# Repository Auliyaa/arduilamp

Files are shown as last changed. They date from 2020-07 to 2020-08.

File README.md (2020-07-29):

# arduilamp

## Description

This repository holds the code as well as the STL files and PCB design to create a RGB lamp with an Arduino board.

The lamp itself supports several modes for speed, brightness & animation, all of which are cycled using 3 buttons connected to the controller.

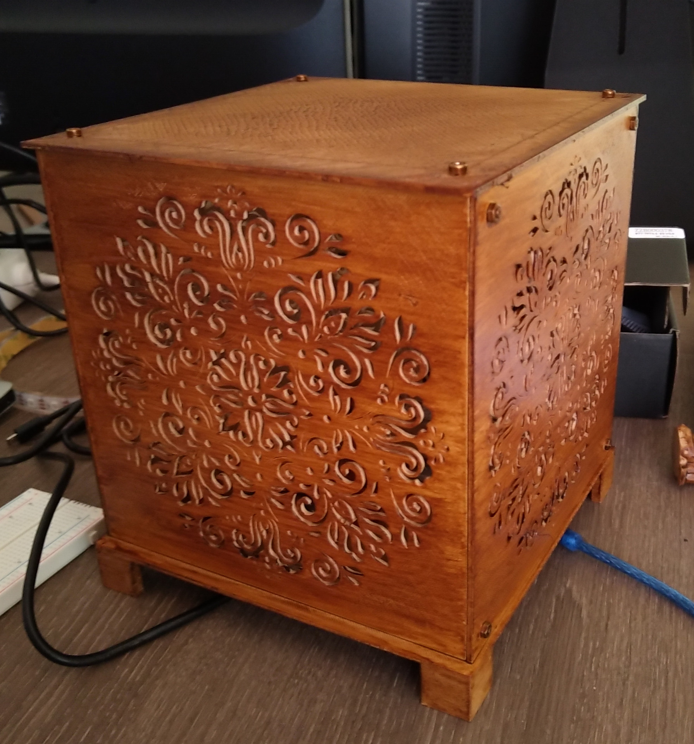
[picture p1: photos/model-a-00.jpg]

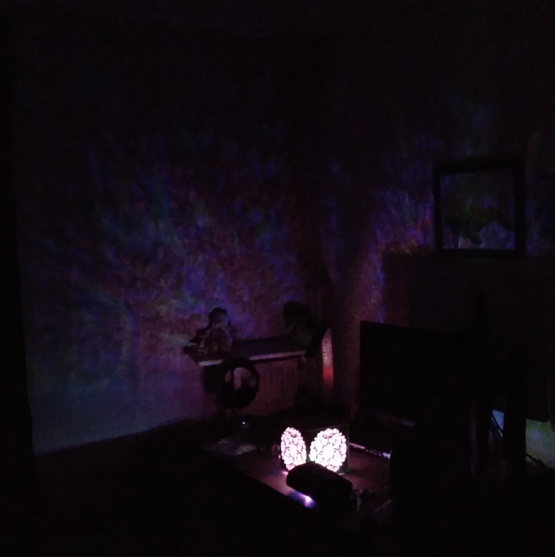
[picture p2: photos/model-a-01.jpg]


## BOM

You'll also need a make of the PCB available under the **pcb** folder as well as a print of one of the lamp models (see the **stl/** folder for details).
The rest of the BOM is the same for all lamp models.

| Piece  | Count  | Link  | Note |
|---|---|---|---|
| Arduino nano ATmega238P | x1  | [Amazon](https://www.amazon.fr/gp/product/B0722YYBSS/ref=ppx_yo_dt_b_asin_title_o07_s00?ie=UTF8&psc=1) | |
| 5V power plug | x1 | [Amazon](https://www.amazon.fr/gp/product/B07G953WC3/ref=ppx_yo_dt_b_asin_title_o09_s01?ie=UTF8&psc=1) | Since those are micro USB, I had to use a [Micro usb to mini USB breakout adapter board](https://www.amazon.fr/gp/product/B07R9SMJKF/ref=ppx_yo_dt_b_asin_title_o02_s00?ie=UTF8&psc=1) |
| WS2812B strip | x1 | [Amazon](https://www.amazon.fr/gp/product/B00JR0MJIU/ref=ppx_yo_dt_b_asin_title_o09_s01?ie=UTF8&psc=1) | |
| 10 kOhm resistor | x3 | [Amazon](https://www.amazon.fr/gp/product/B071LHFQKD/ref=ppx_yo_dt_b_asin_title_o07_s00?ie=UTF8&psc=1) | |
| Push button | x3 | [Amazon](https://www.amazon.fr/gp/product/B01E6SBB5E/ref=ppx_yo_dt_b_search_asin_title?ie=UTF8&psc=1) | |

Not included are tools like wires, soldering iron, a 3D printer and some tools to clean-up your prints.

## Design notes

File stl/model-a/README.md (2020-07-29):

Original design credits to [vishnu1505](https://www.thingiverse.com/thing:2955149).
You'll need to print 2x **Shade_with_holes.STL** and 2x **Shade_with_mount.STL** for the sides. Skip the other files.
Instead use the **Base.stl** and **Top_cover.stl** provided in this repository for the top & bottom pieces.

Those were printed on a Creality Ender-3 using wood PLA.

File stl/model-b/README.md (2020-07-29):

Original design credits to [Agent_Cain](https://www.thingiverse.com/thing:2974862).

I used the original design without modification, using the Top_Hard variant and without printing any of the Plane.stl files.

Then I hot glued the top section over the base after puting a square of 2x2 LEDs inside it.

The code was modified accordingly to set LED group size to 4 (see board.h).

Printed on a Creality Ender 3 with SmartFil white PLA.

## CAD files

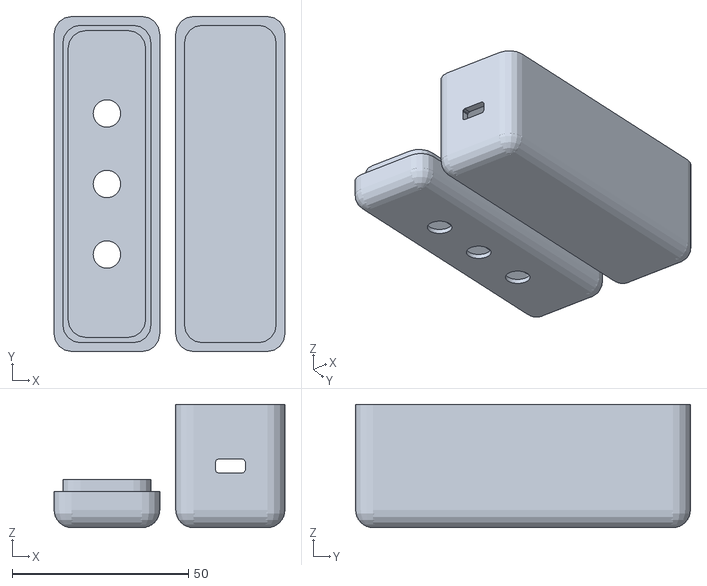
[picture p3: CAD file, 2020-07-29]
stl/electronics-box.stl
65.5 x 95.0 x 35.0

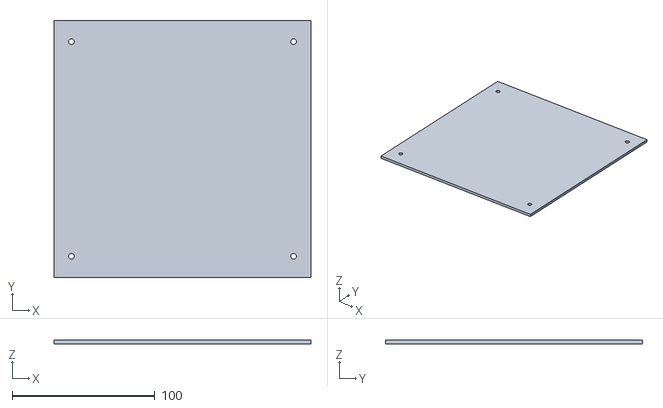
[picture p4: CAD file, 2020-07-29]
stl/model-a/Top_cover.stl
180.0 x 180.0 x 2.50

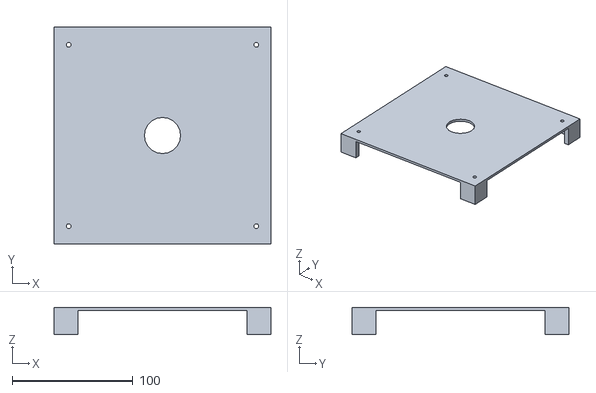
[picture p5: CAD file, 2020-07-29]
stl/model-a/Base.stl
180.0 x 180.0 x 22.5

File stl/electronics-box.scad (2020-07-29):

include <boxes.scad>

translate(v=[0,0,17.5]) difference() {
    union() {
        roundedBox([31,95,35], 5, false);
        translate(v=[0,0,2.5]) roundedBox([31,95,30], 5, true);
    }
    translate(v=[0,0,2.5]) roundedBox([26,90,35], 5, true);
    rotate([90,0,0]) roundedBox([8.5,4,300], 0.75, true);
}

translate(v=[-35,0,5.1]) difference() {
    union() {
        roundedBox([30,95,10.2], 5, false);
        translate(v=[0,0,2.5]) union() {
            roundedBox([30,95,5.2], 5, true);
            roundedBox([25,90,12.2], 5, true);
        }
    }
    translate(v=[0,0,2.5]) roundedBox([22,87,12.3], 5, true);
    translate(v=[0,0,-5.5]) cylinder(h=9, r=3.875, $fn=100);
    translate(v=[0,-20,-5.5]) cylinder(h=9, r=3.875, $fn=100);
    translate(v=[0,20,-5.5]) cylinder(h=9, r=3.875, $fn=100);
}

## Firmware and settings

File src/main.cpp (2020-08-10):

#include <FastLED.h>
#include <Arduino.h>
#include <EEPROM.h>

#include "board.h"

#include "effects/rainbow.h"
#include "effects/random.h"
#include "effects/hue.h"
#include "effects/static.h"
#include "effects/sunlight.h"

// current board mode
#define MODES_CNT 6
effect_t *mode_values[MODES_CNT] = {
    new rainbow_effect_t(),
    new hue_effect_t(),
    new static_effect_t<0>(),
    new static_effect_t<20>(),
    new random_effect_t(),
    new sunlight_effect_t()};
int current_mode = 0;
void current_mode_changed()
{
  if (current_mode >= MODES_CNT) current_mode = 0;
  mode_values[current_mode]->setup();
  FastLED.show();
}

// current board brightness
#define BRIGHTNESS_CNT 5
int brightness_values[BRIGHTNESS_CNT] = { 50, 100, 150, 200, 255 };
int current_brightness = 0;
void current_brightness_changed()
{
  if (current_brightness >= BRIGHTNESS_CNT) current_brightness = 0;
  FastLED.setBrightness(brightness_values[current_brightness]);
}

// current board speed
#define SPEED_CNT 6
int speed_values[SPEED_CNT] = { 0, 2, 5, 30, 65, 100 };
int current_speed = 3;
void current_speed_changed()
{
  if (current_speed >= SPEED_CNT) current_speed = 0;
  mode_values[current_mode]->set_speed(speed_values[current_speed], current_speed, SPEED_CNT);
}

// load/save from/to EEPROM
bool save_eeprom = false; // set to true each time an EEPROM value needs to be updated

void dump_settings()
{
  Serial.print("brightness=");
  Serial.println(brightness_values[current_brightness]);
  Serial.print("speed=");
  Serial.println(speed_values[current_speed]);
  Serial.print("mode=");
  Serial.println(mode_values[current_mode]->name());
}

void save_settings()
{
  int addr = EEADDR;
  EEPROM.put(addr, current_brightness);
  addr += sizeof(current_brightness);
  EEPROM.put(addr, current_speed);
  addr += sizeof(current_speed);
  EEPROM.put(addr, current_mode);

  dump_settings();
}

void load_settings()
{
  int addr = EEADDR;
  EEPROM.get(addr, current_brightness);
  addr += sizeof(current_brightness);
  EEPROM.get(addr, current_speed);
  addr += sizeof(current_speed);
  EEPROM.get(addr, current_mode);

  dump_settings();
}

void init_settings()
{
  for (uint16_t ii=0; ii < EEPROM.length(); ++ii)
  {
    EEPROM.write(ii, 0);
  }
  save_settings();
}

void setup()
{
  FastLED.addLeds<WS2812B, PIN_LED, GRB>(board.leds, LED_COUNT);
  Serial.begin(9600);

  board.btn_brightness.setup();
  board.btn_mode.setup();
  board.btn_speed.setup();

  // uncomment for the first time the board is executed so that the EEPROM is initialized
  //init_settings();

  load_settings();

  current_mode_changed();
  current_speed_changed();
  current_brightness_changed();
}

void loop()
{
  mode_values[current_mode]->loop();
  FastLED.show();

  if (board.btn_brightness.read())
  {
    ++current_brightness;
    current_brightness %= BRIGHTNESS_CNT;
    current_brightness_changed();
    save_eeprom = true;
  }
  if (board.btn_mode.read())
  {
    ++current_mode;
    current_mode %= MODES_CNT;
    current_mode_changed();
    current_speed_changed();
    save_eeprom = true;
  }
  if (board.btn_speed.read())
  {
    ++current_speed;
    current_speed %= SPEED_CNT;
    current_speed_changed();
    save_eeprom = true;
  }

  if (save_eeprom)
  {
    save_settings();
    save_eeprom = false;
  }

  delay(50);
}

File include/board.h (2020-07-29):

#pragma once

#include <FastLED.h>
#include <Arduino.h>

#include "button.h"

// global definitions for the RGB strip
#define LED_COUNT 20

// group leds by color (groups) all leds in the same group will share the same color
#define LED_GROUP_SZ 1
#define LED_GROUP_COUNT (LED_COUNT/LED_GROUP_SZ)

// pin allocation
#define PIN_LED 13
#define PIN_BTN_SPEED 10
#define PIN_BTN_BRIGHTNESS 11
#define PIN_BTN_MODE 12

// start location for EEPROM writing
#define EEADDR 166

struct board_t
{
    CRGB leds[LED_COUNT];

    btn_t<PIN_BTN_SPEED> btn_speed;
    btn_t<PIN_BTN_BRIGHTNESS> btn_brightness;
    btn_t<PIN_BTN_MODE> btn_mode;
};

extern board_t board;

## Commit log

2020-07-06 [develop] adding more effects and fixing animation speed
    [main.cpp]
2020-07-06 [develop] fixed static effect
    [board.h, main.cpp]
2020-07-08 [develop] added support for arduino nano
2020-07-08 [develop] adapted pin layout and added a way to init eeprom
2020-07-08 [develop] added fritzling pcb layout
    [arduilamp.fzz]
2020-07-10 [develop] removed useless comet effect
    [enclosure-bottom.stl, enclosure-top.stl]
2020-07-11 [develop] fixed compiler warning
    [main.cpp]
2020-07-22 [develop] reworked pcb, reworked electronics box
    [arduilamp.fzz, electronics-box.scad, electronics-box.stl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]
2020-07-23 [develop] stl: increase hole size for buttons
    [electronics-box.scad, electronics-box.stl]
2020-07-24 [develop] stl: small tweak & fixes
    [electronics-box.scad, electronics-box.stl]
2020-07-24 [develop] ensure that the box 3d model is properly z-aligned
    [electronics-box.scad, electronics-box.stl]
2020-07-25 [develop] added BOM & link to STL files for the original design
    [Base.stl, Top_cover.stl]
2020-07-29 [develop] support LED groups
2020-07-29 [develop] updated doc with photos & added stl link for model-b
2020-07-29 [develop] fixed speed allowed values
    [main.cpp]
